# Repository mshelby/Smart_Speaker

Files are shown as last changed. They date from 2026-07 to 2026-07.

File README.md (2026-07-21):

# BarrelSat One

**Timeless beauty with modern capability.**

A premium, fully local smart speaker that honors classic proportions and craftsmanship while delivering exceptional modern performance.

## Design Philosophy: Quiet Quality

I believe beautiful objects should feel like they belong to a longer timeline. They should honor classic proportions, craftsmanship, and timeless aesthetics, while quietly incorporating modern functionality and performance.

I’m drawn to classic architecture and traditional methods not for nostalgia, but because they have already proven what is beautiful and enduring over centuries. 

My goal is to take that inherited sense of **Quiet Quality** and pair it with honest modern engineering — so the object doesn’t just look timeless, it also works exceptionally well in the present.

# BarrelSat One

A premium, fully local smart speaker designed as a spiritual successor to the Amazon Echo 4th Gen, built with superior acoustics, thoughtful craftsmanship, and complete privacy.

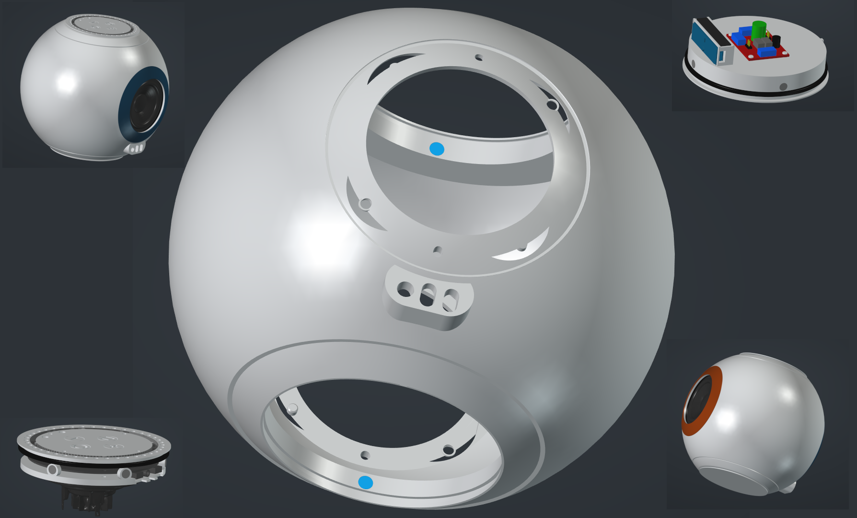
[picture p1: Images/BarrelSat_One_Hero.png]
BarrelSat One - Hero


**BarrelSat One** — Handcrafted with thoughtful engineering and quiet luxury aesthetics.

---
</br></br>
## Current Status
**Progress: ~95% Complete** — Working on fine tuning the print process.

</br></br>
## Gallery

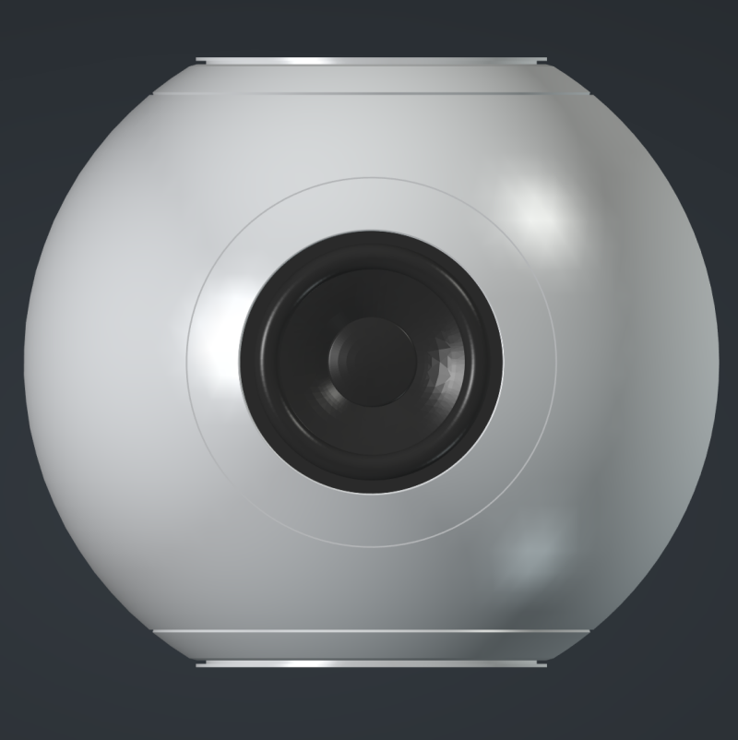
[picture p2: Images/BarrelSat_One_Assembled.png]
BarrelSat One - Assembled


**Fully assembled BarrelSat One**

---

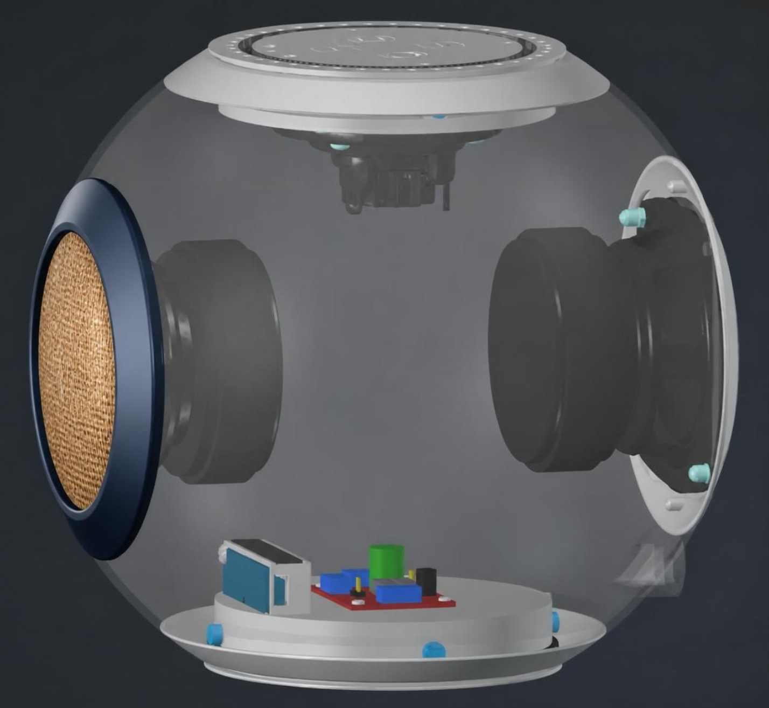
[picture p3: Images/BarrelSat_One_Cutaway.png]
BarrelSat One - Cutaway


**Cutaway view showing internal layout**

---

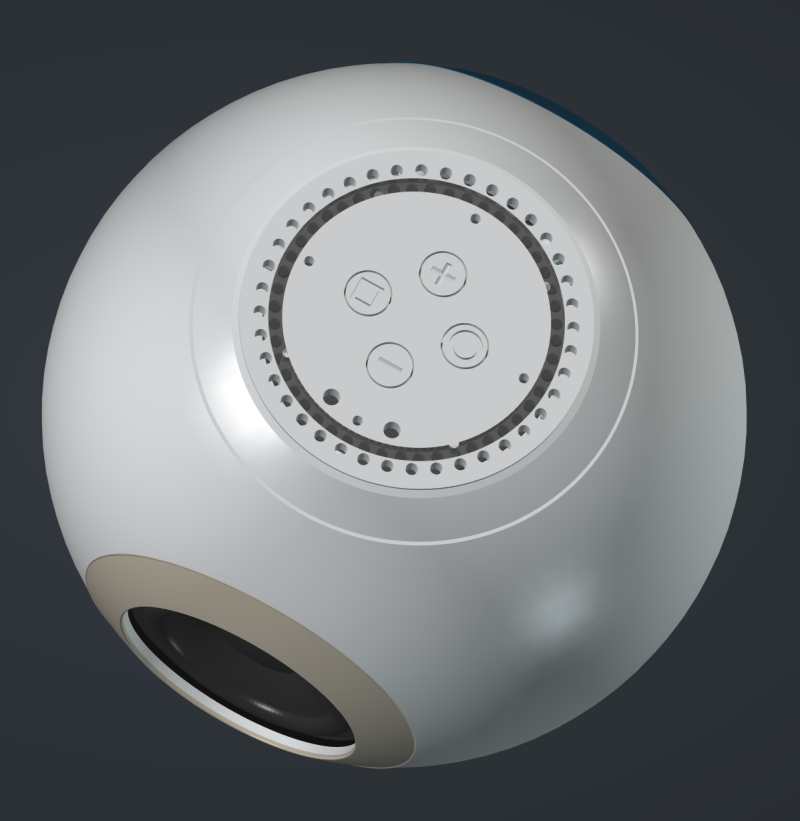
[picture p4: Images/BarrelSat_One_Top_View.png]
BarrelSat One - Top View


**Top module detail with grille and controls**

---

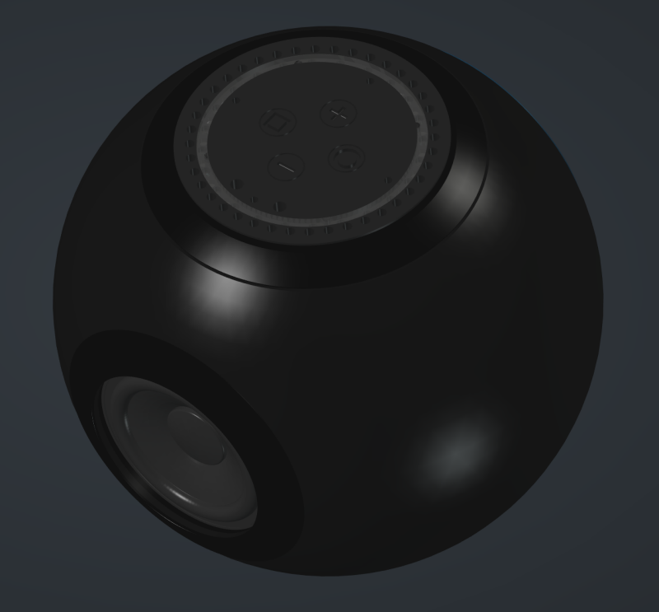
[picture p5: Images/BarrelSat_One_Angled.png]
BarrelSat One - Angled View


**Angled view highlighting possibility of multiple surface finishes**

</br></br>
## Design Architecture

Three-part modular enclosure:

* **Central Barrel** — Spherical form, 200 mm diameter × 175 mm tall with 2.5 mm walls and elegant exterior speaker banding
* **Top Module** — Houses Satellite1 board, upward-firing tweeter, and diffuser ring
* **Bottom Module** — Weighted base with crossover, LD2450 presence sensor, TPU sealing ring, and magnetic attachment

## Key Specifications

* **Drivers**: Dual opposing Dayton Audio PC83-4 3" woofers + Dayton ND25FA-4 upward firing tweeter
* **Acoustic Volume**: Targeting 3.0 liters usable
* **Materials**: PETG with strategic thinning at drivers
* **Sealing**: TPU gaskets + magnetic closure system
* **Integration**: Fully local via Home Assistant + Music Assistant
* **Security**: Privacy-focused local design

## Quick Links

### Documentation
- [Hardware Materials](Docs/Hardware_Materials.md)
- [Design Decisions](Docs/Design_Decisions.md)
- [Build Guide](Docs/Build_Guide.md)

### Source Files
- [Source Files](/Source/)

### Printable Files
- [3mf Print Plates](/3MF_Print_Plates/)
- [STLs](/STLs/)

</br></br>
## Remaining Tasks

See the '[Remaining Tasks](Docs/Remaining_Tasks.md)' file for the detailed punch list.

</br></br>
**Built entirely with Linux open-source software. Modeled in FreeCad and printed with Orca Slicer.** </br>
**Designed in collaboration with Grok (xAI)**

---

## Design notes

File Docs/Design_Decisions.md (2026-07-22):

# Design Decisions

**Last Updated:** July 2026

## Core Philosophy
The 'Quiet Quality' Design Philosophy emphasizes honest engineering, quiet luxury, and timeless minimalism. Inspired by clean functional design, the BarrelSat One prioritizes acoustic performance, serviceability, and a refined "old money" aesthetic.

## Key Decisions
- Spherical Barrel form with 200 mm diameter and ~175 mm height
- 2.5 mm nominal wall thickness.
- Customizable trim bands elegantly framing the speaker openings and top/bottom edges
- Trim rings printed separately for color customization
- Speaker holes on top plate for upward-firing tweeter acoustics
- Modular top and bottom with magnetic closure and TPU sealing gaskets to boost accoustic volume in barrel
- Opposing Dayton PC83-4 woofers + upward Dayton ND25FA-4 tweeter
- Internal volume target ~3.0 liters usable
- Intentional 1 mm shadow gaps at top and bottom modules for visual separation and easy removal
- Glued trim rings (permanent, seamless decorative attachment)

## Color, Texture & Surface Finish

### Barrel Main
- **Color:** Concrete Gray Matte  
- **Approximate Hex:** `#DEDEDE` (warm light gray / concrete)
- **Why chosen:** Provides a soft, neutral, architectural base that feels substantial and timeless. Matte finish reduces glare, hides minor layer lines, and supports the quiet luxury aesthetic. Complements both dark modules and colored trim rings without competing with them.

### Speaker Trim Rings (Front & Rear) + Upper / Lower Trim Rings
- **Color:** Matte Navy  
- **Approximate Hex:** `#1E3A5F` (deep navy)
- **Why chosen:** Creates elegant contrast against the light gray barrel while remaining refined and classic. Navy reads as “quiet luxury” rather than bright or trendy. Separate printed rings allow easy color experimentation (wood-look, charcoal, etc.) without reprinting the entire barrel.

### Modules (Top & Bottom Caps)
- **Color:** Concrete Gray Matte (same as Barrel Main)
- **Approximate Hex:** `#A8A29E` (warm light gray / concrete)
- **Why chosen:** Matches barrel main for a clean aesthetic while allowing individual trim lines to appear more prominent.

### Diffuser Ring
- Translucent / Clear PETG (or light smoke gray) so LEDs glow cleanly through without harsh hotspots.

### Surface Finish Notes
- Primary finish: Matte PETG throughout for a soft, high-end tactile feel.
- Optional: Orca Slicer “Fuzzy Skin” on the barrel exterior (still under evaluation — test on a sample first).
- No high-gloss surfaces preferred — they fight the quiet, refined character of the design.

All decisions prioritize the balance of premium appearance, printability, and sound quality.

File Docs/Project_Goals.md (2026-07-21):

# Project Goals

A premium, fully local smart speaker designed as a spiritual successor to the Amazon Echo 4th Gen, but built with superior acoustics, thoughtful craftsmanship, and complete privacy through Home Assistant integration.

**Key Objectives:**
- Superior acoustic performance with dual opposing woofers and optimized internal volume
- Premium feel through substantial weight, clean lines, and refined details (including intentional 1 mm shadow gaps)
- Modular design for serviceability and ease of assembly
- Timeless, minimalist aesthetics with no visible external fasteners
- Honest engineering that prioritizes function and long-term reliability
- Demonstrate that a carefully designed open, local device can stand on equal footing with both high-end passive/active speakers and leading commercial smart speakers

**Quiet Quality Design Philosophy**  
Inspired by refined minimalism and functional clarity, this project prioritizes honest engineering, acoustic performance, and timeless aesthetics while remaining fully local and privacy-focused.

---

## Benchmark Devices for Later Comparison

One explicit project goal is to evaluate whether BarrelSat One can stand on equal footing with premium commercial products — both in pure acoustic quality and in the overall “smart speaker” experience (integration, presence sensing, voice, multi-room, etc.). The following devices are recorded here as the primary reference points for future listening tests, measurements, and qualitative assessment.

### Primary Smart Speaker Benchmarks
| Device | Why It Matters | Notes for Comparison |
|---|---|---|
| **Amazon Echo (4th Gen)** | Original design target / “gold standard” for form factor, size, and everyday smart-speaker performance | Direct spiritual successor goal. Compare bass extension, midrange clarity, voice assistant usefulness (local vs cloud), presence detection, and overall “plug-and-play polish.” |
| **Apple HomePod (2nd generation)** | Current high-water mark for computational audio and seamless ecosystem integration in a compact premium smart speaker | Compare spatial audio processing, automatic room correction, build quality/feel, and privacy posture. |
| **Sonos Era 300** (or Era 100) | Leading multi-room / high-fidelity smart speaker with strong app ecosystem and Trueplay tuning | Compare stereo imaging, app experience, multi-room capability, and value. |

### High-End Audio Speaker References (~$1,000–$1,500 class and related)
| Device / Brand | Approx. Price Class | Why It Matters | Notes for Comparison |
|---|---|---|---|
| **Bowers & Wilkins** (Formation Flex, or similar compact powered models; also their classic continuum cone + tweeter loading philosophy) | $600–$1,200+ | Explicitly referenced during design for tweeter loading / rear-chamber ideas and overall premium compact speaker DNA | Compare treble refinement, cabinet rigidity, and the sense of “expensive” sound from a small enclosure. |
| **KEF LSX II** (or LSX II LT) | ~$1,200–$1,400 / pair | Highly regarded coaxial Uni-Q driver technology, accurate imaging, and modern premium compact wireless performance | Excellent reference for clarity, soundstage precision, and how much performance is possible from a small, well-engineered active enclosure. |
| **Dynaudio** (e.g. Xeo or small active/bookshelf models in this range) | ~$1,000–$1,500 | Danish quiet-luxury reputation for natural midrange and refined, non-fatiguing sound | Strong benchmark for “does this sound expensive and effortless?” listening tests. |
| **Focal** (small powered or bookshelf models, e.g. Chora / Aria compact or equivalent) | ~$1,000–$1,400 | French high-end brand known for dynamic, detailed treble and solid cabinet construction | Useful for evaluating transient response and perceived refinement. |
| **Other quiet-luxury compact references** (Naim Mu-so level design language, Sonus Faber entry compacts, etc.) | $1,000–$1,500+ | Broader context for what “premium small speaker” looks, feels, and sounds like | Subjective “heirloom quality” and industrial design comparison. |

### Evaluation Criteria (to be used later)
- Bass extension and control relative to size
- Midrange naturalness and vocal clarity
- Treble smoothness and air
- Imaging / soundstage
- Overall dynamic capability
- Build quality, weight, and tactile premium feel
- Privacy and local-control advantages
- Ease of daily use within Home Assistant + Music Assistant
- Visual and industrial design coherence (“Quiet Quality”)

These benchmarks are not about claiming to “beat” every commercial product on every metric. They exist so that, after real-world listening and measurement, we can honestly assess how close BarrelSat One comes to standing on equal footing with both the best smart speakers and true high-end compact audio devices in the $1,000–$1,500 class.

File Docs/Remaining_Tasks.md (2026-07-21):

# BarrelSat One – Remaining Tasks

**Last Updated:** July 2026  
**Overall Progress:** ~95% Complete — Focus is now on test printing, fitment refinement, and final polish.

---

## 1. Print Preparation
- [ ] Finalize support strategy for the large one-piece Barrel_Main (tree/organic supports, orientation, brim/raft)
- [ ] Decide on Orca Slicer “Fuzzy Skin” (test on a small sample first)
- [ ] Verify all STL exports have clean geometry and acceptable file size / resolution
- [ ] Confirm magnet pocket diameters and depths for snug N52 6×3 mm fit
- [ ] Double-check cable block opening sizes for the flat USB-C and 3.5 mm extensions
- [ ] Print small test pieces first: gaskets, trim rings, weight lid, magnet pockets

## 2. First Test Prints & Fitment
- [ ] Print and test-fit all TPU gaskets
- [ ] Print and glue-test Upper / Lower / Speaker trim rings
- [ ] Print Bottom Module (Weight_Cylinder + Lid) and verify magnet click + TPU seal
- [ ] Print Top Module stack (Tweeter_Deck, Top_Panel, Diffuser) and check board clearance, button feel, and shadow gap
- [ ] Print full Barrel_Main and verify speaker mount fit, internal clearances, and module insertion
- [ ] Note any dimensional adjustments needed (sanding, reprint, or FreeCAD tweaks)

## 3. Assembly & Integration
- [ ] Fill weight compartment with steel shot + epoxy and cure fully
- [ ] Install all magnets (secure with adhesive if needed)
- [ ] Mount woofers with gaskets and self-tapping screws / lock nuts
- [ ] Apply speaker fabric (optional but recommended for premium look)
- [ ] Route cables cleanly and stuff light polyfill
- [ ] Full dry assembly of Top + Barrel + Bottom and check magnetic engagement + 1 mm shadow gaps

## 4. Functional & Acoustic Testing
- [ ] Power-up and verify Satellite1 board, Music Assistant playback, and LD2450 presence detection
- [ ] Listening tests vs Amazon Echo 4th Gen (primary benchmark)
- [ ] Subjective comparison notes against high-end references (KEF LSX II class, B&W compact, Dynaudio, etc.)
- [ ] Evaluate bass extension, midrange clarity, treble smoothness, and overall “premium feel”
- [ ] Confirm no buzzes, rattles, or air leaks under moderate volume

## 5. Documentation & Repo Polish
- [ ] Upload final gallery images (Assembled, Cutaway, Top detail, Angled)
- [ ] Update this Remaining Tasks list as items are completed
- [ ] Update Open_Questions_Risks.md after key decisions (especially Fuzzy Skin and print supports)
- [ ] Final pass on Build_Guide.md with any real-world tips learned during first prints
- [ ] Optional: Add a simple Changelog or version note once first complete unit is validated

## 6. Nice-to-Have / Future
- [ ] Measure actual internal acoustic volume of finished barrel
- [ ] Consider minor FreeCAD refinements based on print feedback
- [ ] Multi-unit color experiments (different trim ring filaments)
- [ ] Longer-term durability notes (magnets, TPU, PETG aging)

---

**Notes**  
Check items off as they are completed. Move resolved risks to the “Resolved” section of Open_Questions_Risks.md. Keep this list living and concise.

**Current Focus:** Test printing and fitment validation.

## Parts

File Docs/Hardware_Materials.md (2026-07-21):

# Hardware & Materials List

#### This is an exhaustive list of absolutely every material used to create the project. Project builders may already have some of these tools & materials, or suitable substitutes. Not every item will need purchasing for each unit built! Some items contain quantaties suitable for building multiple units, but were listed as purchased for affordability. Project builers are encouraged to economize where possible! These items were purchased to acieve the goals of the project... i.e. "quiet quality / quiet luxury." Amazon and other links referenced due to fast shipping and ubiquitous access. Project builders might also consider buying from the stores at [Future Proof Homes](https://futureproofhomes.net/collections/all-products) to support that project as well!  

<br><br>

## Main Audio Components

| Item | Qty | Link | Notes | Price Each | Price Total |
|---|-----|---|---|---|---|
| Satellite1.1 Dev Kit | 1 | [FutureProofHomes](https://futureproofhomes.net/products/satellite1-pcb-dev-kit) | With the Satellite1 Dev Kit, you can create your own ultra-powerful voice assistant, smart speaker, and multi-sensor all in one product — fully compatible with the Home Assistant platform. | $69.99 | $69.99 |
| Dayton Audio PC83-4 3" Full-Range Driver | 2 | [Amazon](https://www.amazon.com/dp/B0751BDJZX) | Main woofers. Amazon sometimes sells them used for less $$ | $22.70 | $45.40 |
| Dayton Audio ND25FA-4 1" Soft Dome Tweeter | 1 | [Amazon](https://www.amazon.com/Dayton-Audio-ND25FA-4-Neodymium-Tweeter/dp/B00GB96TG8/ref=sr_1_1) | Upward firing tweeter | $17.86 | $17.86 |
| GODIYMODULES Adjustable 2-Way Crossover | 1 | [Amazon](https://www.amazon.com/dp/B0DP5X3MS8) | Passive crossover board | $8.99 | $8.99 |
| HLK-LD2450 mmWave Presence Sensor + Antenna | 1 | [Amazon](https://www.amazon.com/LD2450-Tracking-Sensing-Distance-HLK-LD2450/dp/B0G91PYF8Z/ref=sr_1_12) | Presence detection | $26.71 | $26.71 |

<br><br>

## Cables & Connectivity

| Item | Qty | Link | Notes | Price Each | Price Total |
|---|-----|---|---|---|---|
| USB-C Extension Cable (8 inch) | 1 | [Amazon](https://www.amazon.com/dp/B0CTDNBZ5S) | 2 pack, 90 Degree USB-C Extension Cable Flat 8inch.USB2.0 C Male to Female Adapter | $11.99 | $11.99 |
| 3.5mm Right Angle Stereo Extension (10 inch) | 1 | [Amazon](https://www.amazon.com/dp/B017PT1EGM) | 2PACK 10 inch 3-Pole 3.5mm Male Right Angle to 3.5mm Female Stereo Audio Cable Extension | $6.99 | $6.99 |
| JST-XH 2.54mm 2-pin Male Connector | 1 | [Amazon](https://www.amazon.com/dp/B0CZHH5D1Q) | 200mm Cable Wire, JST-XH2.54mm 2 Pin Male Connector Plug | $6.49 | $6.49 |

<br><br>

## Fasteners & Magnets

| Item | Qty | Link | Notes | Price Each | Price Total |
|---|-----|---|---|---|---|
| N52 Neodymium Magnets 6x3mm | 1 pack | [Amazon](https://www.amazon.com/dp/B09QHSB2XM) | Need 18 total | $7.99 | $7.99 |
| Assorted M3 x 6mm/10mm/16mm Self-Tapping Screws | 1 kit | [Amazon](https://www.amazon.com/Self-Tapping-Screws-Phillips-Carbon-Plastic/dp/B0BPM8J5F5/ref=sr_1_3?s=industrial) | qty 2 - M3 x6mm, qty 4 - M3 x10mm, Qty 4 - M3 x16mm | $7.99 | $7.99 |
| M3 x4mm Flat Head Screws | 1 pack | [Home Depot](https://www.homedepot.com/p/Everbilt-M3-0-5-x-6mm-Zinc-Flat-Head-Phillips-Drive-Machine-Screw-4-Pieces-837951/321071637) | For mounting sidewall speakers - Need 4 screws, 2 per speaker, Can also use 5mm or 6mm length | $1.98 | $1.98 |
| m3 Lock Nut / Acorn Nut | 1 pack | [Home Depot](https://www.homedepot.com/p/Everbilt-M3-0-5-Stainless-Steel-Lock-Nut-4-Pieces-837221/321071866) | For mounting sidewall speakers - Need 4, 2 per speaker | $1.98 | $1.98 |

<br><br>

## Filaments & Fabrics

| Item | Qty | Link | Notes | Price Each | Price Total |
|---|-----|---|---|---|---|
| Concrete Gray, Matte PETG (For Barrel & Modules)| 1 spool | [Amazon](https://www.amazon.com/eSUN-Filament-Temperature-Resistance-Printing/dp/B0GGHRB52X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) | eSUN PETG Matte Filament 1.75mm, 3D Printer Filament Matte PETG, Temperature Resistance and Bending Resistance, 1KG Spool (2.2 LBS) | $17.99 | $17.99
| Translucent PETG (For Diffuser) | 1 spool | [Amazon](https://www.amazon.com/iSANMATE-Translucent-Filament-Dimensional-Specifically/dp/B0GSJR5LT9/ref=sr_1_5) | iSANMATE Rapid PETG Translucent Gray 3D Printer Filament 1.75mm,50-400mm/s High Speed Clear PETG Filament. If you can find a small spool, it's cheaper. You don't need much! | $14.99 | $14.99 |
| Matte Navy PETG (For Trim Rings) | 1 spool | [Amazon](https://www.amazon.com/IEMAI-Filament-Printer-Dimensional-Accuracy/dp/B0GGBLVB2S/ref=sr_1_2) | IEMAI Matte PETG Filament 1.75mm Navy Blue 1kg, Smooth Matte Finish 3D Printer Filament with Minimal Layer Lines & Low Warping. It's a gray barrel, so almost anything can match it. Try a [wood](https://www.amazon.com/stores/page/E78B37D8-0CEA-4FD4-9D60-E214499DE244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) filament! | $19.99 | $19.99 |
| Lotactree Black TPU 95A (For Gaskets & Sealing Rings) | 1 spool | [Amazon](https://www.amazon.com/dp/B0FMRJN1MN) | Black, High Rubber-Like, Flexible 95A Grade TPU Filament, 1.75mm 250g. Important to get 95A grade if possible | $8.99 | $8.99 |
| Black/Gray/Tan Cloth Speaker Fabric | 1 | [Amazon](https://www.amazon.com/dp/B0FG73WXSQ?smid=A1THAZDOWP300U) | accoustically Transparent woven fabrics used for a more upscale aesthetic  | $13.99 | $13.99 |

<br><br>

## Build Materials

| Item | Qty | Link | Notes | Price Each | Price Total |
|---|-----|---|---|---|---|
| Fine Steel Shot: Fine S110 Steel Shot | 1 | [Amazon](https://www.amazon.com/Steel-Shot-S-110-Blasting-Media/dp/B09318JKZR/ref=sr_1_5) | Source: 5 lb bag recommended (one bag covers multiple units, though Only 450g (24 tablespoons) is needed per unit). | $29.99 | $29.99 |
| 2-Part Epoxy Resin | 1 kit | [Amazon](https://www.amazon.com/TotalBoat-Artist-Epoxy-Resin-Crystal-Clear/dp/B0DYKMHQ21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) | Mix 3oz (90ml) with steel shot until fully coated and pour into the weight cylinder. Allow full cure (typically 24–72 hours depending on epoxy) before final assembly | $8.99 | $8.99 |
| Polyfill | 1 bag | [Amazon](https://www.amazon.com/dp/B0F6MZ36K9) | For acoustic damping inside the barrel | $7.99 | $7.99 |
| Adhesive | 1 | [Amazon](https://www.amazon.com/Gorilla-Clear-Glue-ounce-Bottle/dp/B06WD6R96X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) | Gorilla Glue -Clear, General purpose adhesive | $6.99 | $6.99 |

<br><br>

## Tools & Miscellaneous Hardware

| Item | Qty | Link | Notes | Price Each | Price Total |
|---|-----|---|---|---|---|
| Phillips Screw Driver | 1 | [Amazon](https://www.amazon.com/Precision-Screwdriver-Zoikuloi-Professional-Electronics/dp/B0F1FKMGPK/ref=sr_1_13_sspa) | I used a phillips driver, but choose whatever driver your screw head requires | $3.99 | $3.99 |
| Rotary Tool | 1 | [Harbor Freight](https://www.harborfreight.com/07-amp-rotary-tool-kit-80-piece-58999.html) or [Amazon](https://www.amazon.com/XIFOWE-Polishing-Cordless-Electric-Attachments/dp/B0DPKF7V65/ref=sr_1_8) | These work nicely if you decide to sand or paint the project. | $9.99 or $24.99 | $9.99 |
| Speaker connectors & Crimping Kit | 1 | [Amazon](https://www.amazon.com/Electrical-Connectors-0-25-2-5mm%C2%B2-Ratcheting-Assortment/dp/B0FKG479X5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) | You will need a few female end connectors and a crimping tool for connecting the JST cables to the speakers | $12.99 | $12.99 |

<br><br>
****

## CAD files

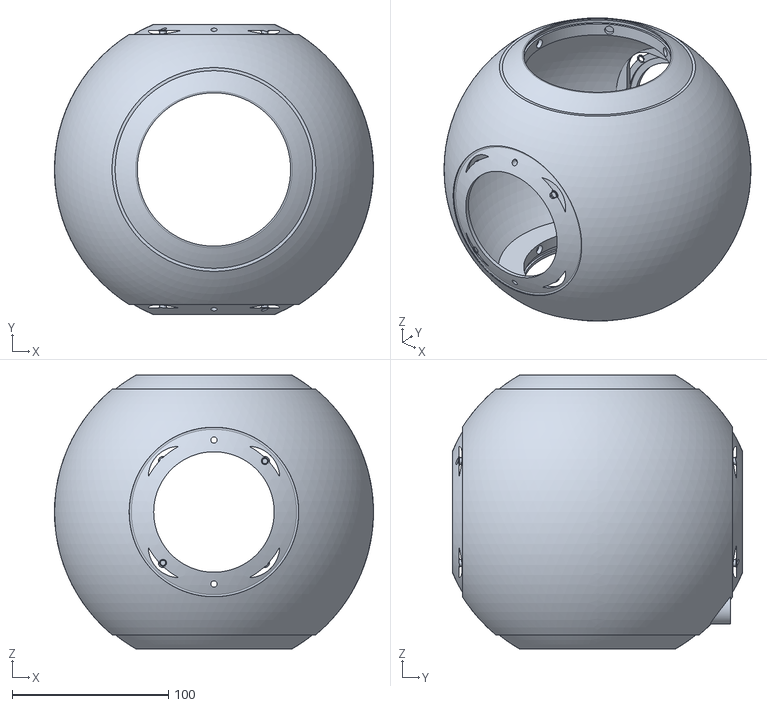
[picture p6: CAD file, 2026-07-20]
STLs/Plain_Barrel/Barrel_Main.stl
203.9 x 185.7 x 175.0

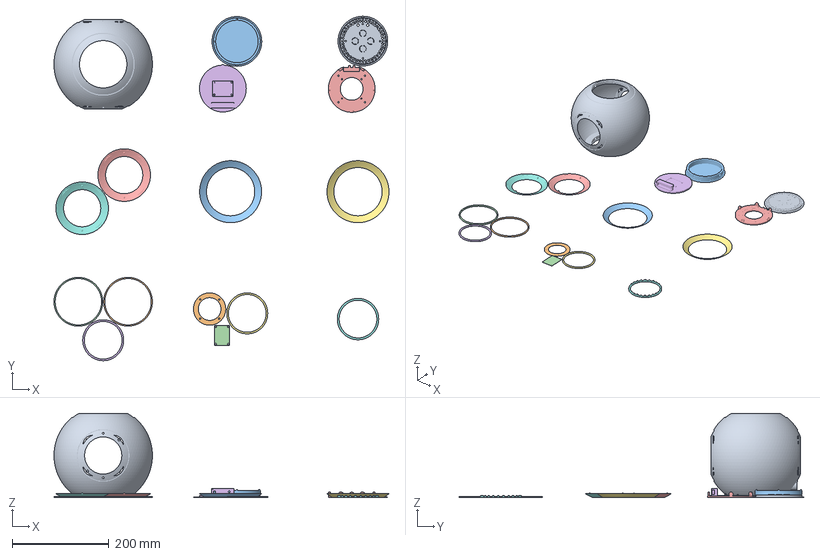
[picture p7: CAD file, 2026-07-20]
3MF_Print_Plates/BarrelSat_One-Printables.3mf
694.2 x 713.9 x 175.0 mm
Barrel
Top Module Sealing Gasket
Upper Trim Ring
Bottom Module Sealing Gasket
Speaker Trim Ring 1
Speaker 1 Gasket
Speaker 2 Gasket
Speaker Trim Ring 2
Top Plate
Tweeter Gasket
Weight Cylinder
Crossover Board Gasket
Tweeter Deck
Weight Cylinder Lid
Lower Trim Ring
Diffuser Ring

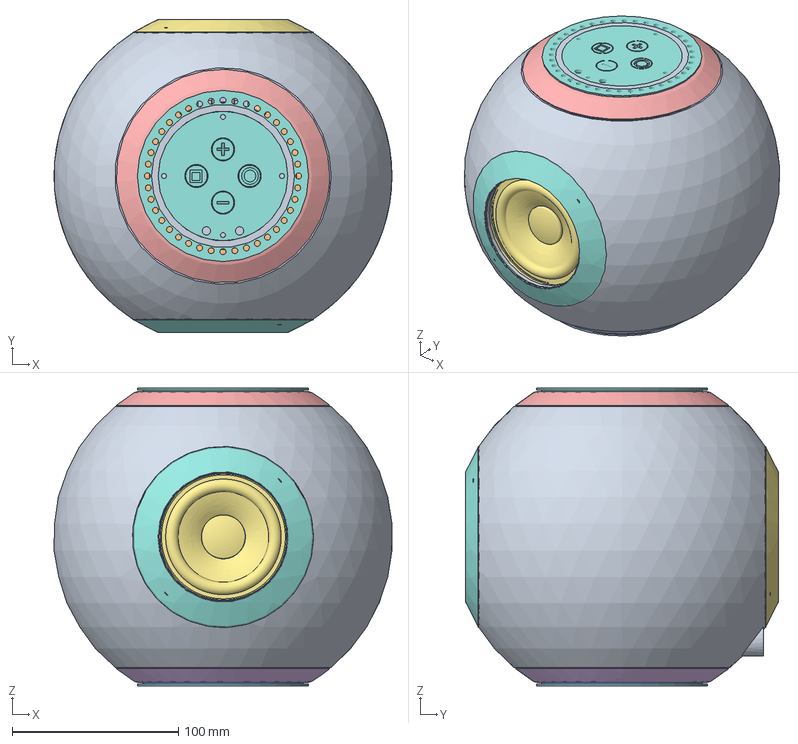
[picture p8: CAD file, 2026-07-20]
Source/BarrelSat_One.FCStd
203.4 x 188.4 x 179.0 mm
Barrel_Main
Gasket_Lower_Module
Gasket_Upper_Module
Gasket-Tweeter
Gasket-Crossover_Board
Gasket_Rear_Speaker
Gasket_Front_Speaker
Top_Panel
Diffuser
Tweeter_Deck
Weight_Cylinder
Weight_Cylinder_Lid
Upper_Trim_Ring
Lower_Trim_Ring
Rear_Speaker_Trim_Ring
Front_Speaker_Trim_Ring
Satellite1 Board & Hat
HLK-LD2450 Presence Sensor
HLK-LD2450 Bluetooth Antenna
GODIYMODULES Passive Crossover Board BODP5X3MS001
Speaker_Fasteners
Bottom Module Screws
Top Module Screws
Tweeter Screws
Magnets in Lower Barrel Wall
Magnets in Upper Barrel Wall
Magnets in Weight Cylinder
Magnets in Upper_Module
Tweeter_ND25F-4
Back_Speaker_PC83-4
Front_Speaker_PC83-4

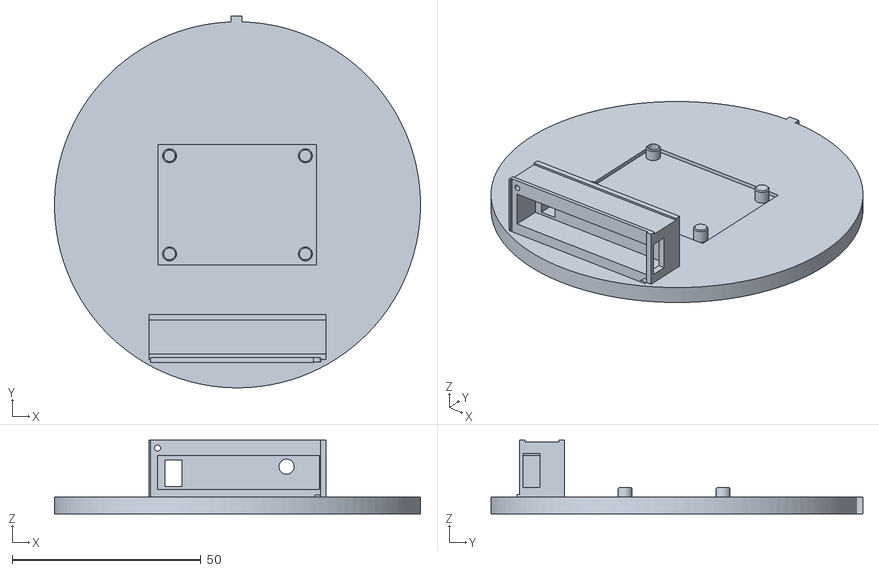
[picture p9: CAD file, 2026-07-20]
STLs/Bottom_Module/Weight_Cylinder_Lid.stl
97.0 x 98.5 x 19.5

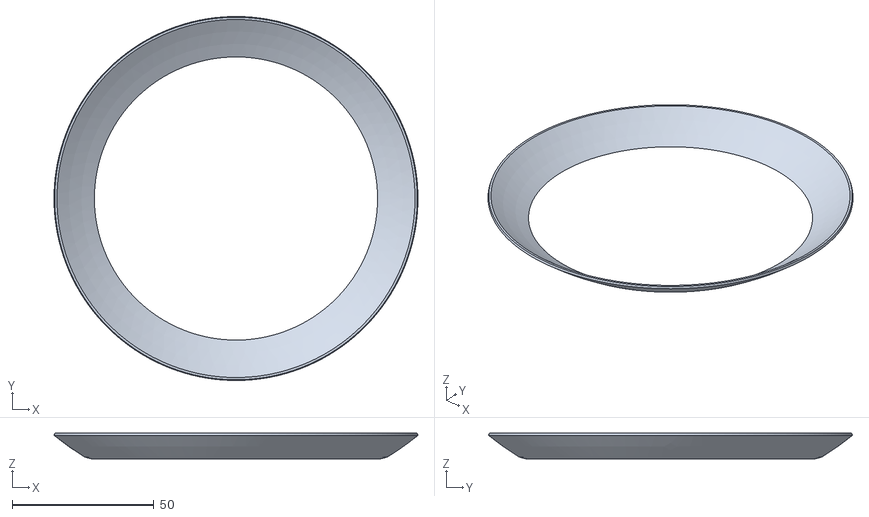
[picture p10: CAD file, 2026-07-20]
STLs/Plain_Barrel/Lower_Trim_Ring.stl
128.4 x 128.4 x 9.00

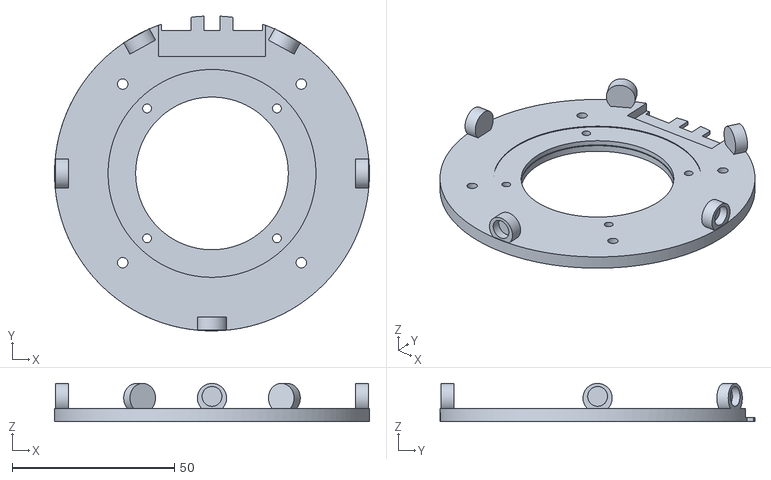
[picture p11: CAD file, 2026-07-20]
STLs/Top_Module/Tweeter_Deck.stl
97.0 x 96.9 x 11.8

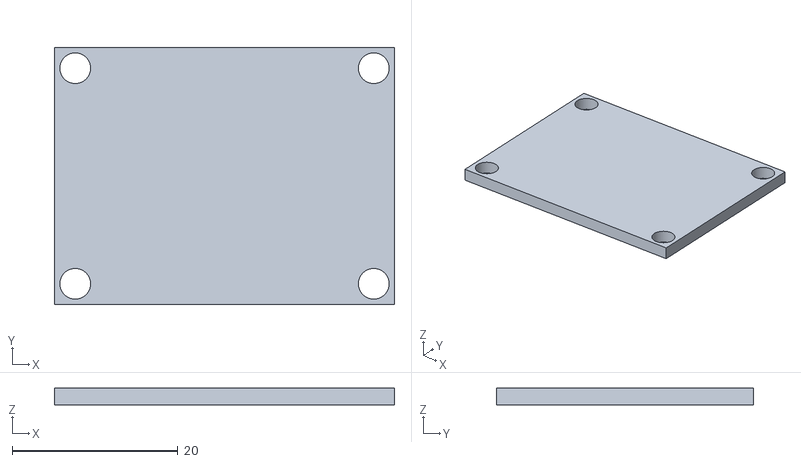
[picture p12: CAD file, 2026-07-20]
STLs/TPU_Gaskets/Gasket-Crossover_Board.stl
41.0 x 31.0 x 2.00

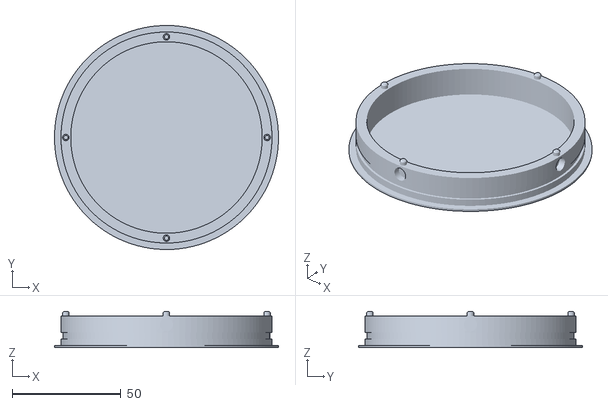
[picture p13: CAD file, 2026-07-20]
STLs/Bottom_Module/Weight_Cylinder.stl
103.0 x 103.0 x 16.6

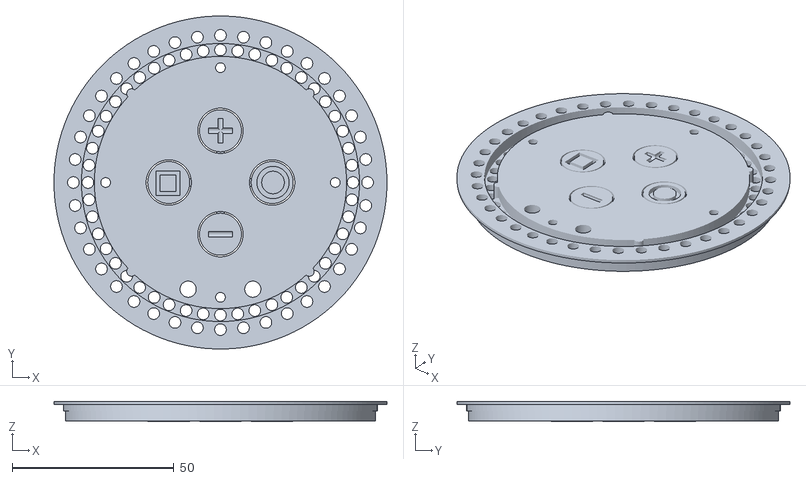
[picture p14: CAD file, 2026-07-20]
STLs/Top_Module/Top_Panel.stl
103.0 x 103.0 x 6.25

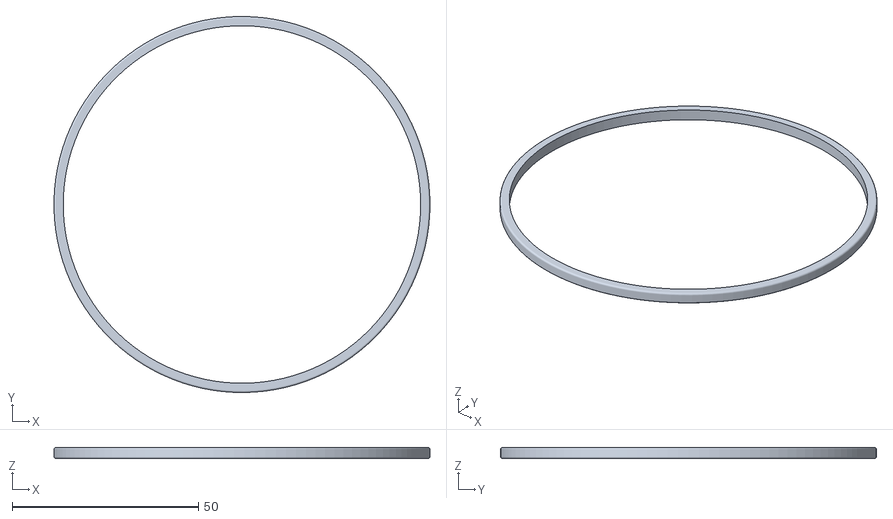
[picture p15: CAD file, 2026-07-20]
STLs/TPU_Gaskets/Gasket_Upper_Module.stl
101.0 x 101.0 x 3.00

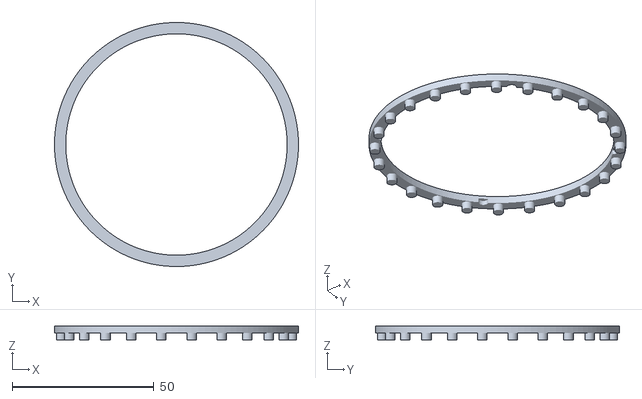
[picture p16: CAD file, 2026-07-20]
STLs/Top_Module/Diffuser.stl
86.0 x 86.0 x 5.00

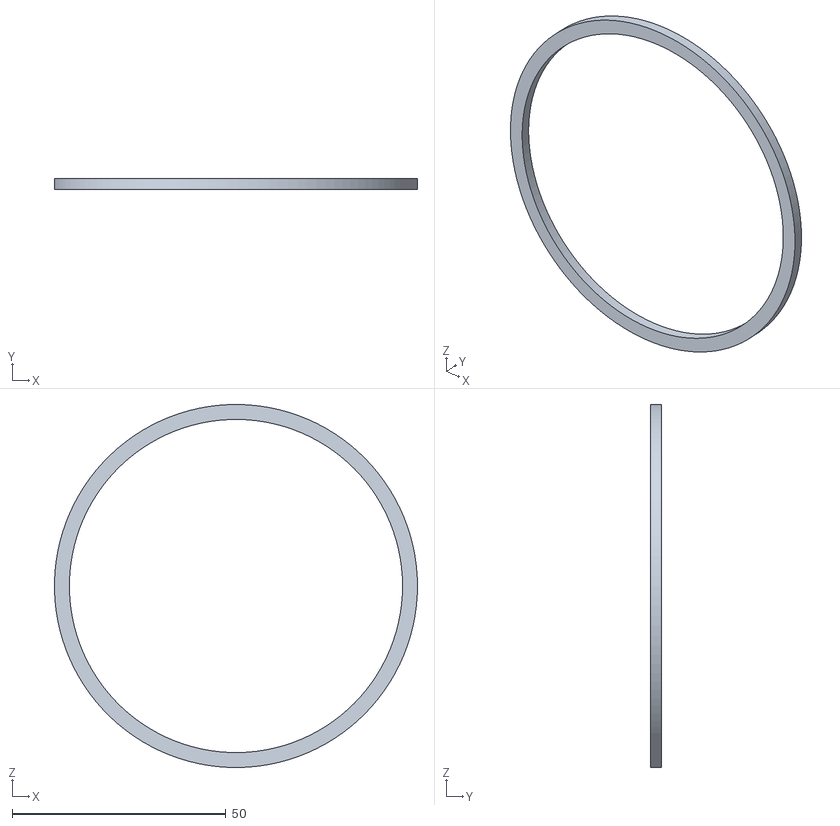
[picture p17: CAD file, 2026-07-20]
STLs/TPU_Gaskets/Gasket_Front_Speaker.stl
85.0 x 2.50 x 85.0

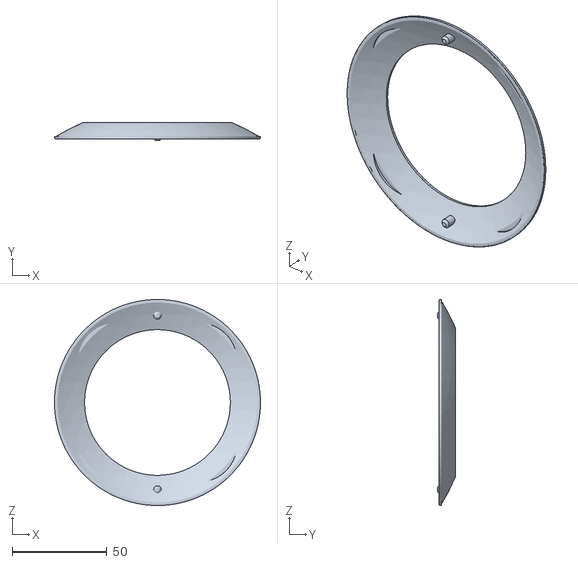
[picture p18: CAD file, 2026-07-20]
STLs/Plain_Barrel/Rear_Speaker_Trim_Ring.stl
108.9 x 9.71 x 108.9

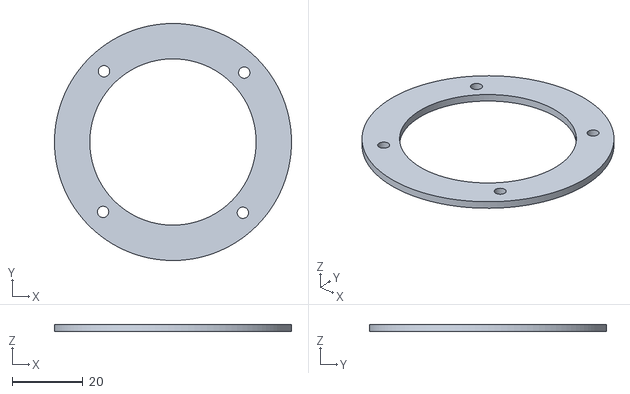
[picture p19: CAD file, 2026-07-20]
STLs/TPU_Gaskets/Gasket-Tweeter.stl
67.0 x 67.0 x 2.00

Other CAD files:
STLs/Plain_Barrel/Upper_Trim_Ring.stl
STLs/Plain_Barrel/Front_Speaker_Trim_Ring.stl
STLs/TPU_Gaskets/Gasket_Lower_Module.stl
STLs/TPU_Gaskets/Gasket_Rear_Speaker.stl
Source/Backup/Barrel_Main.stl
Source/Backup/Cable_Block.stl

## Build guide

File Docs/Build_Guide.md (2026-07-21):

# BarrelSat One – Build Guide

**Last Updated:** July 2026  
**Status:** First complete draft – ready for test printing and refinement

This guide walks you through printing, preparing, and assembling one complete BarrelSat One unit. It assumes you are using the STLs and 3MF plates in this repository and Orca Slicer (or equivalent).

---

## 1. Required Materials

Refer to the full [Hardware & Materials List](Hardware_Materials.md) for links, quantities, and notes.

**Key categories:**
- Filaments (Concrete Gray matte PETG, Translucent PETG, Matte Navy PETG, Black TPU 95A)
- Drivers (2× Dayton PC83-4, 1× Dayton ND25FA-4)
- Electronics (Satellite1.1 Dev Kit, crossover, LD2450 + antenna)
- Magnets, screws, steel shot, epoxy, polyfill, adhesive, speaker fabric
- Tools (precision screwdriver, crimping kit, rotary tool optional)

---

## 2. Print Order & Recommended Settings

Print in this approximate order so you can test-fit as you go:

1. **TPU Gaskets** (all of them) – quick and useful for fit checks
2. **Diffuser Ring** (It's a small item, and only thing using translucent PETG)  
3. **Trim Rings** (Front Speaker, Rear Speaker. Uses different color PETG filament than all remaining prints)
4. **Trim Rings** (Upper & Lower Barrel Rings)  
5. **Bottom Module** (Weight_Cylinder + Weight_Cylinder_Lid)  
6. **Top Module** (Tweeter_Deck, Top_Panel, Diffuser)  
7. **Barrel_Main** (the large one-piece barrel)

### Suggested Starting Settings (PETG)
- Layer height: 0.2 mm (0.16–0.2 mm for visible surfaces)
- Wall loops: 3–4
- Infill: 15–25% (gyroid or cubic)
- Supports: Tree or organic where needed (especially barrel interior features and overhangs)
- Bed adhesion: Brim or raft for the large barrel
- Fuzzy Skin: Optional – test on a small sample first (still an open decision)

### TPU Settings
- Print slow (20–40 mm/s)
- Retraction tuned for your setup
- No supports usually needed for the flat gaskets

Use the provided `BarrelSat_One-Printables.3mf` as a starting point and adjust for your printer.

---

## 3. Post-Processing

- Remove supports carefully (especially inside the barrel and around speaker mounts).
- Lightly sand any visible layer lines on exterior surfaces if desired (matte filament hides a lot).
- Test-fit all magnets into their pockets – they should be snug. Secure with a drop of CA or Gorilla Glue (clear) if needed.
- Dry-fit all TPU gaskets.
- Clean the cable block openings so the extension cables seat cleanly.

---

## 4. Weight Compartment Assembly (Bottom Module)

1. Print and clean the Weight_Cylinder and Lid.
2. Mix steel shot with 2-part epoxy until fully coated.
3. Pour into the cylinder. Target ~250–450 g total mass depending on final feel (start lower and add if desired).
4. Allow full cure (24–72 hours).
5. Install the lid (pegs + optional glue or screws).
6. Install magnets into the lid / cylinder wall pockets and secure.
7. Attach the TPU sealing ring (Gasket_Lower_Module) into its groove.

---

## 5. Top Module Assembly

1. Mount the Dayton ND25FA-4 tweeter to the Tweeter_Deck with the TPU tweeter gasket.
2. Route the flat USB-C and 3.5 mm extension cables through the slim channels in the spacer / deck.
3. Install the Satellite1 board + HAT onto the top side of the deck / Top_Panel (use the designed standoffs / screw holes).
4. Install the Diffuser ring (clear/translucent PETG) so LEDs glow cleanly through it.
5. Install magnets into the Top Module side walls / pockets.
6. Attach Gasket_Upper_Module.
7. Verify button feel and that the 1 mm shadow gap will be present when installed on the barrel.

---

## 6. Barrel Preparation

1. Place speaker gaskets (Front & Rear) between driver and inner wall, then mount the two Dayton PC83-4 woofers from the inside using the designed pegs and secure with flat head M3 x4mm machine screws + lock nuts or acorn nuts.
2. Optionally affix acoustic fabric (black / gray / vintage tone) to speaker trim rings using flexible adhesive (Gorilla Glue Clear).
3. Install Front and Rear speaker trim rings (glue recommended – permanent decorative attachment).
4. Install Upper and Lower trim rings (glue).
5. Install any internal cable guides or just route the extension cables cleanly down to the cable block.
6. Lightly stuff polyfill in the chamber for damping (do not overstuff – preserve volume).

---

## 7. Final Assembly

1. Slide the Bottom Module up into the barrel until the TPU ring seats and the magnets click.
2. Connect all wiring (crossover, presence sensor, speakers, extensions to Sat1 board).
3. Lower the Top Module into place until magnets engage and the 1 mm shadow gap is even.
4. Verify all functions: power, audio via Music Assistant, presence detection, buttons, LED glow through diffuser.
5. Place on a soft surface or add foam feet if desired.

---

## 8. Acoustic & Fit Notes

- Opposing woofers + upward tweeter + ~3 L target volume is the acoustic foundation.
- Polyfill improves midrange control and reduces internal reflections.
- Magnetic + TPU sealing keeps the chamber as airtight as practical while remaining fully serviceable.
- If any fit is tight, lightly sand the mating surfaces or check magnet polarity.

---

## 9. Optional Finishing Touches

- Fuzzy Skin sample test on a scrap before committing to the full barrel.
- Light clear coat or matte varnish only if desired (test first – matte PETG already looks premium).
- Custom fabric colors for different units (black, medium gray, warm vintage).
- Serial number or small engraved mark inside the bottom lid if building multiple units.

---

## 10. Troubleshooting & Iteration

- Document any dimensional deviations after first prints.
- Update this guide and the Remaining Tasks list with real-world notes.
- Real acoustic testing (frequency response, bass extension, listening comparisons to Echo 4th Gen) is the final validation step.

---

**Built with FreeCAD + Orca Slicer on Linux.**  
**Designed in collaboration with Grok (xAI).**

Happy building — take your time and enjoy the process.

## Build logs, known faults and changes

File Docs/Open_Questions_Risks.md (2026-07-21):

# Open Questions & Risks

## Remaining Items
- Final STL export quality and print supports strategy for large barrel
- Decision on using Orca Slicer Fuzzy Skin on surfaces
- Real-world acoustic testing after printing
- Long-term durability of magnets and TPU gaskets
- Finalizing fitment of printed objects and subcomponents (i.e. are holes in cable block correctly sized for snug fit of cables?)

## Resolved
- Magnet and gasket strategy locked in
- Weight cylinder volume capacity (425g - 480g)

Last Updated: July 2026

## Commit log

2026-06-22 Add Hardware & Materials list
2026-06-23 Update Design Decisions with new 192mm barrel and optimized dimensions
2026-06-27 Updated Open_Questions_Risks.md with current project status
2026-07-03 Create stl
2026-07-06 Update Design_Decisions.md with tightened content and last updated date
2026-07-06 Update Open_Questions_Risks.md with current status
2026-07-07 Add Barrel_Main.stl and organize project files
2026-07-07 Move Barrel_Main.stl into STLs/ folder
2026-07-08 Organize project: Flattened Tweeter Deck
    [Tweeter_Deck.stl]
2026-07-10 Added: Orca-Slicer Plates
    [BarrelSat_One.3mf]
2026-07-20 added all files
    [BarrelSat_One.FCStd, Barrel_Main.stl, Cable_Block.stl]
2026-07-20 added 3mf print plates
    [BarrelSat_One-Printables.3mf]
2026-07-20 Added STL files
    [Barrel_Main.stl, Front_Speaker_Trim_Ring.stl, Lower_Trim_Ring.stl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]
2026-07-20 added all STLs
    [Diffuser.stl, Gasket-Crossover_Board.stl, Gasket-Tweeter.stl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]
2026-07-20 added details to .3mf plates
    [BarrelSat_One-Printables.3mf]
2026-07-20 Expand Build Guide into full skeleton with print order, assembly, and finishing steps
2026-07-20 Expand Remaining_Tasks into clear categorized punch list for print prep, assembly, testing, and polish
